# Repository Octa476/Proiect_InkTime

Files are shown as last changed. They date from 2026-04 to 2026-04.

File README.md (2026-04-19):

# Proiect_InkTime

Schematic, PCB design si 3D modeling pentru ceasul InkTime in cadrul proiectului de la materia TSC.
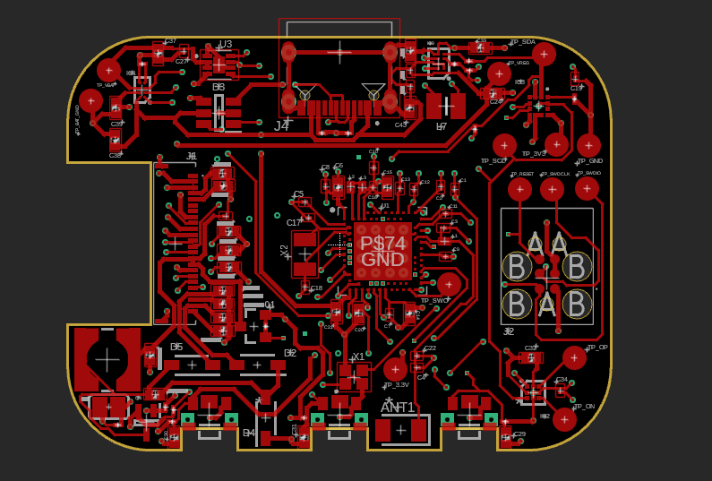
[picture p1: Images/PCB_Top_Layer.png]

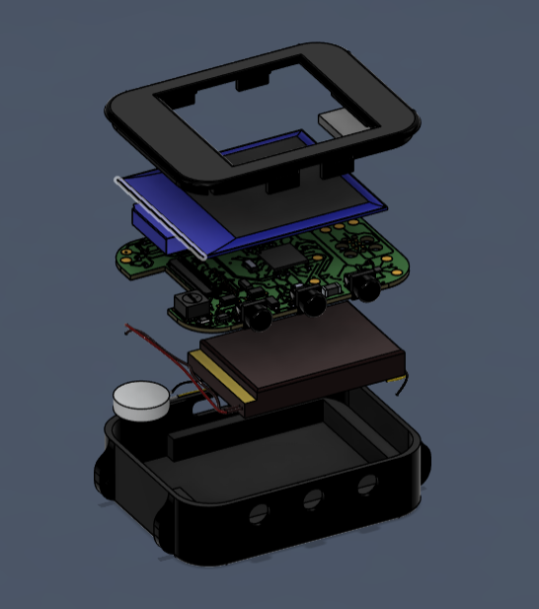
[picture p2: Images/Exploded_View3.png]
Exploded View


## Diagrama Bloc

Diagrama bloc a proietului (o varianta destul de minimala, dar suficienta pentru a intelege cum interactioneaza componentele intre ele) este prezenta in folder-ul root proiectului in varianta HTML si a fost realizata folosind [www.drawio.com](https://www.drawio.com/).
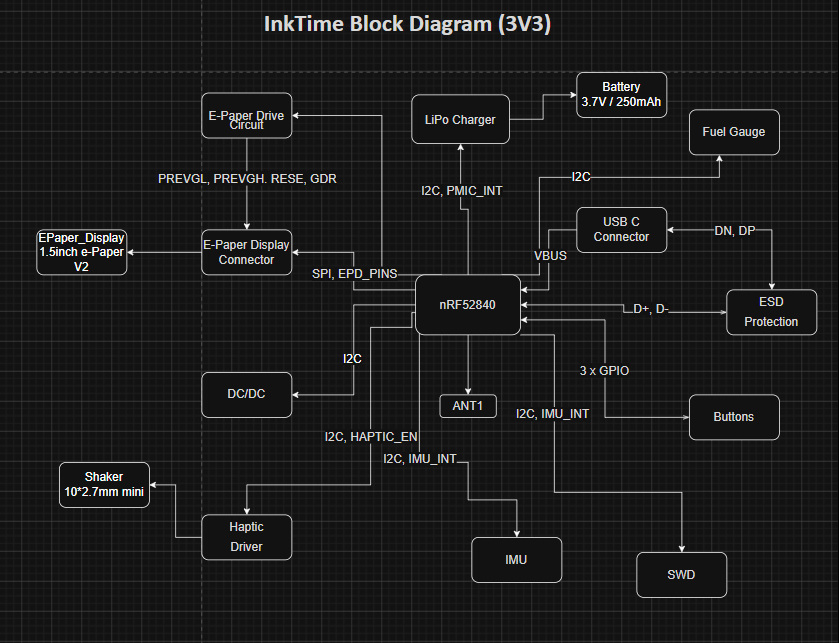
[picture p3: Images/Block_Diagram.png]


## BOM
Un Bills of Materials cu componentele folosite in cadrul acestui proiect.

### Componente active
 
| Component | Part Number | Package | Function | JLCPCB Part | Datasheet |
|---|---|---|---|---|---|
| MCU | nRF52840-QIAA-R | aQFN73 (7x7) | Microcontroller + BLE + USB | [C190794](https://jlcpcb.com/partdetail/Nordic_Semicon-NRF52840_QIAA_R/C190794) | [Datasheet](https://infocenter.nordicsemi.com/pdf/nRF52840_PS_v1.8.pdf) |
| Charger / Power Path | BQ25180YBGR | DSBGA-8 | Li-Ion/LiPo charger with power path | [C3682423](https://jlcpcb.com/partdetail/TexasInstruments-BQ25180YBGR/C3682423) | [Datasheet](https://www.ti.com/lit/ds/symlink/bq25180.pdf) |
| Buck-Boost Regulator | RT6160AWSC | WLCSP-15 | 3.3V system rail regulator | [C7065276](https://jlcpcb.com/partdetail/Richtek_Tech-RT6160AWSC/C7065276) | [Datasheet](https://www.richtek.com/assets/product_file/RT6160A/DS6160A-05.pdf) |
| Fuel Gauge | MAX17048G+T10 | DFN-8 (2x2) | Battery SOC monitoring | [C2682616](https://jlcpcb.com/partdetail/AnalogDevices-MAX17048G_T10/C2682616) | [Datasheet](https://www.analog.com/media/en/technical-documentation/data-sheets/MAX17048-MAX17049.pdf) |
| Accelerometer | BMA421 | LGA-12 (2x2) | Step counting + motion wake | [C5242966](https://jlcpcb.com/partdetail/Bosch_Sensortec-BMA421/C5242966) | [Datasheet](https://www.bosch-sensortec.com/media/boschsensortec/downloads/datasheets/bst-bma421-ds004.pdf) |
| Haptic Driver | DRV2605LDGSR | VSSOP-10 | ERM motor driver with effects library | [C527464](https://jlcpcb.com/partdetail/TexasInstruments-DRV2605LDGSR/C527464) | [Datasheet](https://www.ti.com/lit/ds/symlink/drv2605l.pdf) |
| PFET (EPD power) | SI2301CDS | SOT-23 | E-paper display power gating | [C10487](https://jlcpcb.com/partdetail/Changjiang_Electronics_Tech_CJ-SI2301CDS/C10487) | [Datasheet](https://www.vishay.com/docs/68749/si2301cds.pdf) |
| USB ESD Protection | USBLC6-2SC6Y | SOT-23-6 | ESD protection on USB data lines | [C7519](https://jlcpcb.com/partdetail/Stmicroelectronics-USBLC6_2SC6Y/C7519) | [Datasheet](https://www.st.com/resource/en/datasheet/usblc6-2.pdf) |
 
### Conectori & Componente electromecanice
 
| Component | Part Number | Package | Function | JLCPCB Part | Datasheet |
|---|---|---|---|---|---|
| FPC Connector (Display) | Molex 503480-2400 | 24-pin 0.5mm FPC | E-paper display FPC connection | [C2857160](https://jlcpcb.com/partdetail/Molex-5034802400/C2857160) | [Datasheet](https://www.molex.com/en-us/products/part-detail/5034802400) |
| USB Type-C Connector | KH-TYPE-C-16P | 16-pin SMD | USB charging + data | [C2765186](https://jlcpcb.com/partdetail/Kinghelm-KH_TYPE_C_16P/C2765186) | [Datasheet](https://datasheet.lcsc.com/lcsc/2012121836_Kinghelm-KH-TYPE-C-16P_C2765186.pdf) |
| Buttons (x3) | EVP-AKE31A | SMD tactile | Up / Down / Enter navigation | [C2845028](https://jlcpcb.com/partdetail/Panasonic-EVP_AKE31A/C2845028) | [Datasheet](https://industrial.panasonic.com/cdbs/www-data/pdf/ATV0000/ATV0000CE3.pdf) |
| SWD Debug Header | TC2030-IDC | Tag-Connect 6-pin | SWD programming + debug | - | [Datasheet](https://4donline.ihs.com/images/VipMasterIC/IC/TGCN/TGCN-S-A0008988129/TGCN-S-A0008988129-1.pdf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) |
| Antenna | 2450AT18B100E | SMD 3216 | 2.4 GHz BLE chip antenna | [C5179427](https://jlcpcb.com/partdetail/Johanson_Technology-2450AT18B100E/C5179427) | [Datasheet](https://www.johansontechnology.com/datasheets/2450AT18B100/2450AT18B100.pdf) |
 
### Componente Pasive
 
| Component | Value | Package | Qty | Function |
|---|---|---|-----|---|
| Capacitors (EPD) | 1uF/50V | 0402 | 9 | E-paper driver capacitors |
| Capacitors (decoupling) | 100nF | 0201 | 5 | MCU + peripheral decoupling |
| Capacitors (crystal load) | 12pF | 0201 | 4 | 32MHz + 32.768kHz crystal loads |
| Capacitors (bulk) | 4.7uF | 0402 | 4 | MCU power rail bulk decoupling |
| Capacitors (charger) | 1uF | 0402 | 3 | BQ25180 CIN/CSYS/CBAT |
| Capacitors (power) | 22uF | 0402 | 2 | RT6160 input capacitors |
| Capacitors (USB) | 4.7uF | 0402 | 1 | DECUSB capacitor |
| Resistors (I2C pull-up) | 10k | 0201 | 2 | I2C SDA/SCL pull-ups |
| Resistors (USB CC) | 5.1k | 0201 | 2 | USB Type-C CC1/CC2 pull-downs |
| Inductor (DC/DC) | 10uH | 0402 | 1 | nRF52840 REG1 DC/DC inductor |
| Inductor (buck-boost) | 0.47uH | 2012 | 1 | RT6160 power stage inductor |
| Crystal | 32 MHz | 2016 | 1 | HFXO for MCU + radio |
| Crystal | 32.768 kHz | 3215 | 1 | LFXO for RTC timekeeping |
 
### Componente asamblate manual
 
| Component | Description | Datasheet |
|---|---|---|
| E-Paper Display | 1.54" 200x200 e-paper panel (connected via 24-pin FPC) | [Datasheet](https://www.tme.eu/Document/0ca57a8ffbcd57b5bca53252eb9d6ec3/WSH-12561.pdf)
| LiPo Battery | 3.7V / 250mAh lithium polymer cell | [Datasheet](https://www.tme.eu/Document/b9e12bf26ad0ba929a22ab5d58f022cd/AKY0106.pdf) |
| ERM Motor | Vibration motor (LCM1027B3605F, wire-soldered) | [Datasheet](https://www.mouser.com/pdfDocs/ProductOverview_DFRobot-FIT0774.pdf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) |
| Case | 3D-printed case (SLS/MJF or FDM prototype) | [Soon](https://www.youtube.com/watch?v=xm3YgoEiEDc&list=RDxm3YgoEiEDc&start_radio=1) |

## Descrierea functionalitatii hardware

### **I2C**: LiPo Charger, DC/DC, IMU, Fuel Gauge, Haptic Driver;
### **SPI**: E-Paper Display Connector;

### Sheet1:
- **LiPo Charger** este folosit pentru a incarca bateria;
- **DC/DC** este un stabilizator de tensiune si este folosit pentru a oferi o tensiune stabila de 3V3 intregii placi;
- **IMU** este un accelerometru, fiind utilizat pentru determinarea acceleratiei pe cele 3 axe, numararea pasilor, etc;
- **nRF52840** este microcontroller-ul placutei si controleaza si orchestreaza intreaga functionalitate a acesteia;
- **SWD** - este mufa pentru conectorul de debug;

### Sheet2:
- **E-Paper Drive Circuit** este folosit pentru a controla display-ul si a oferii tensiuni de alimentare potrivite;
- **E-Paper Display Connector** - conectorul ce face legatura intre display si restul sistemului;
- **Fuel Gauge** este o componenta care indica nivelul de incarcare al bateriei;
- **USB C Connector** este mufa usb;
- **ESD Protection** este un modul ce protejeaza placuta de descarcarile elctrostatice ce pot aparea in utilizarea zilnica a ceasului;
- **Haptic Driver** este folosit pentru a controla vibratia shaker-ului;
- **Buttons** vor indeplini anumite functii in interfata cu utilizatorul (mai multe detalii in implementarea software);

## Descriere pini nRF52840 (randul de sus, sens invers trigonometric)

| Pin | Descriere |
|---|---|
| VDD | alimentarea la 3V3 |
| DCC | power regulation | 
| DEC4 | power regulation |
| VSS | GND |
| P0.31/AIN7-4 | nefolosit |
| P0.02/AIN0 | SCK - pinul de clock pentru protocolul SPI prin care comunica conectorul de display |
| P0.02/AIN0 | MOSI - master output slave in, folosit pentru comunicarea SPI |
| P1.15-12 | nefolosit |
| DEC2 | GND, power regulation |
| P1.12-11 | nefolosit |
| VDD | 3V3 |
| XC2, XC1 | pini pentru sursa de ceas X1 de 32MHz |
| DEC3 | GND |
| DEC6 | power regulation |
| VSS_PA | alimentare antena |
| ANT | pin folosit pentru legarea la antena |
| P0.10/NFC2 | pin folosit probabil pentru ca Fuel Gauge sa anunte microcontroller-ul cand tensiunea bateriei ajunse sa fie mai mica decat un prag anume |
| P0.09/NFC1 | nefolosit |
| DEC5 | GND, power regulation |
| P1.07-03 | nefolosit |
| P1.02 | buton down |
| P1.01 | controleaza tensiunea de alimentare a display-ului prin driver |
| SWDIO, SWDCLK | pini utilizati pentru depanarea si programarea microcontroller-ului |
| VDD | 3V3 |
| VSS_PAD | GND |
| P1.00 | SWO - pin utilizat pentru depanarea si programarea microcontroller-ului |
| P0.25-19 | nefolosit |
| P.18/RESET | maretul pin de reset |
| P0.17, P0.16, P0.15 | pini folositi pentru tranzactionarea cu display-ul |
| P0.13, P0.14| buton ent, buton up |
| D-, D+ | pini folositi la tranzactionarea datelor de la USB; folosesc tranmisie diferentiala |
| VBUS | alimentarea la 5V a unui USB |
| DEC3V3 | GND (ciudat putin, SoC interesant) |
| DCCH | nefolosit |
| VDDH, VDD | 3V3 |
| P0.12 | enable pentru driverul haptic |
| P0.11 | folosit pentru atentiona microcontroller-ul de posibile hazarde de alimentare; este controlar de Lipo Charger |
| P1.09 | nefolosit |
| P1.08, P0.08 | pini de intrerupere pentru modulul de IMU |
| P0.07, P0.06 | pini folositi de protocolul I2C |
| P0.05/AIN3 | chip select pentru display |
| P0.04/AIN2, P0.27, P0.26 | nefolosit |
| XL2, XL1 | pini pentru sursa de ceas X2 de 32KHz |
| DEC1 | GND, power regulation |

## Aspecte de design

- am ales sa realizez PCB-ul pe 4 straturi. Am un plan top, unul bottom, un plan de masa pe layer-ul de sub top si un plan de 3V3 pe layer-ul de deasupra lui bottom;
- am pozitionat antena in partea de jos a placii, langa butoane si am decupat straturile de cupru de sub aceasta;
- am folosit via in pad si am din aceasta cauza cateva erori pe care le-am acceptat deoarece era singura solutie viabila;
- am ales sa am un nivel de detaliu mediu in cadrul modelarii 3D a bateriei, display-ului si shaker-ului
- am conectat shaker-ul si bateria prin fire la test pad-urile asociate lor;
- am curbat conectorul flex al display-ului pentru a se potrivi in concectorul de pe PCB folosind comanda bend pentru metal sheets;
- am folosit niste inlocuitori pentru modelul 3D al unor piese, deoarece nu am putut identifica un model exact al footprint-ului din schematic sau footprint-ul nu era unul specificat tehnic (ex: PERFECT_0402, JUMPER_SJ, etc);
- am realilzat un exploded view vertical, in care sunt prezente piesele dezasamblate ale ceasului;
- am inclus cateva screenshot-uri de pe parcursul dezvolatarii proiectului in folderul Images;

## Observatii personale

Proiectul a fost extrem de muncitoresc si plin de frustrari din mai multe puncte de vedere. In primul rand, nu am fost "scoliti" in a utiliza la capacitate scazuta spre medie facilitatile de care dispune aplicatia Fusion Autodesk, fapt ce a dus la un loop aproape infinit de vizionat tutoriale si incercari repetate inutile de trage o curba in spatiu pentru desenarea firelor de legatura (un umil exemplu). Mi-as fi dorit ca laboratoarele sa prezinte mai in detaliu functionalitatile esentiale in realizarea proiectului si consider ca nu este o virtute faptul ca ne-am descurcat singuri, deoarece timpul pe care il avem este deja extrem de limitat (da, am invatat multe, pe cont propriu sau prin viu grai, dar ar fi fost mult mai usor sa fim instruiti macar putin mai mult).

Dupa aceasta critica constructiva, as dorii totusi sa felicit ideea de a propune un astfel de proiect. A fost un proces interesant de design, atat la nivel de PCB, cat si modelare 3D, si simt ca m-a ajutat sa ma dezvolt pe plan ingineresc. Am invatat sa ma descurc singur, sa incerc, m-am enervat de multe ori, dar intr-un final am reusit sa fixez un fir exact in pozitia in care imi doream.
Fun fact, am avut un bug in fusion care imi bloca coada de task-uri si ajunsesem sa am in jur de 240 de task-uri in processing, fapt ce imi bloca orice incercare de a exporta un fisier 3D. Din fericire, am rezolvat aceasta problema printr-o comanda text inteligenta.

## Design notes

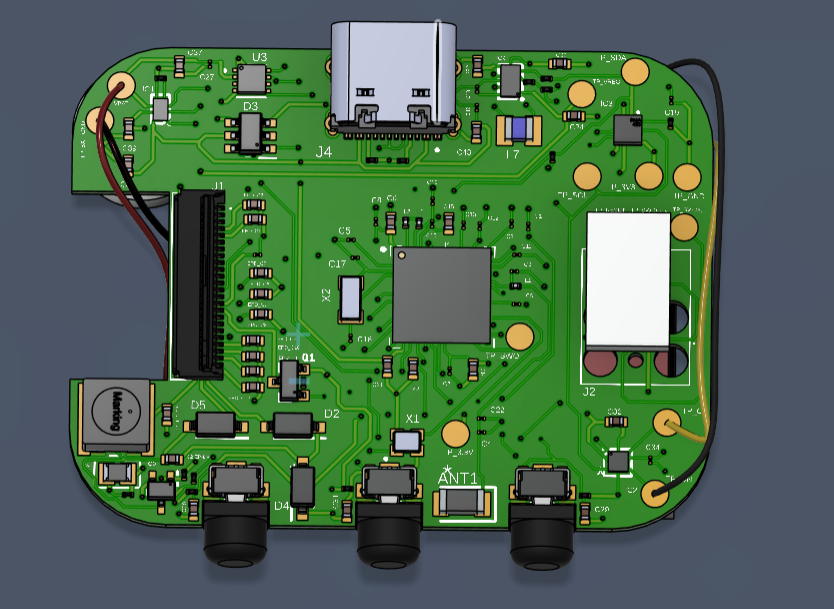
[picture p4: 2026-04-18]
Images/PCB_3D_Wires.png

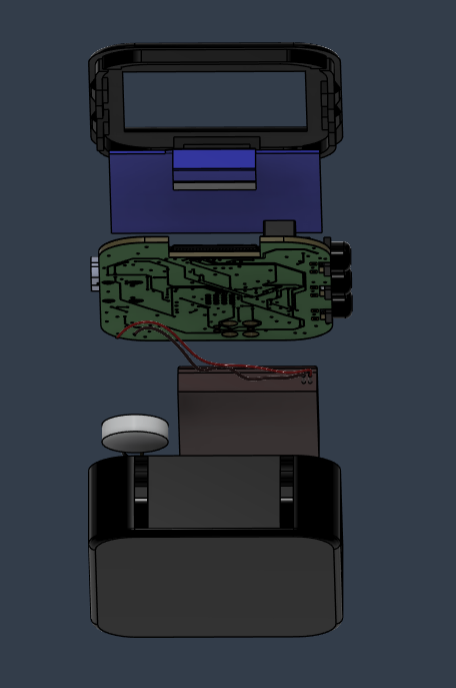
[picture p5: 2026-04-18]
Images/Exploded_View2.png

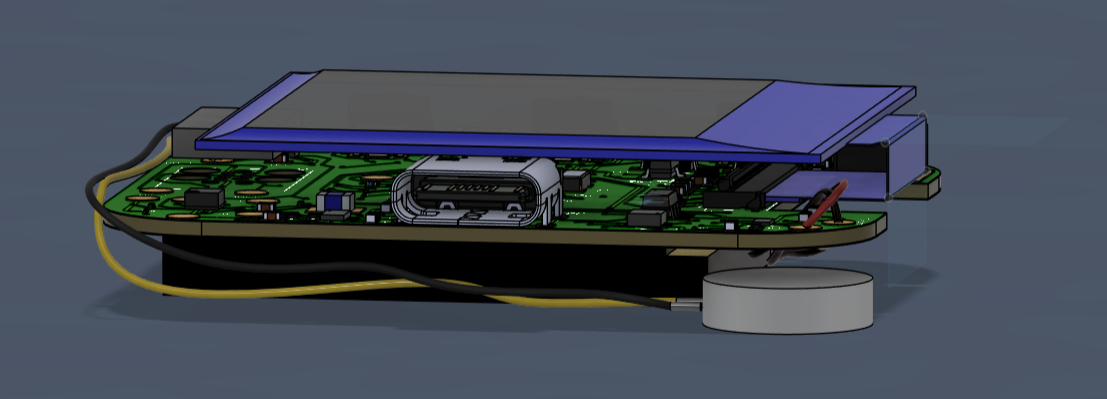
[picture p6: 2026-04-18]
Images/PCB_Side_View.png

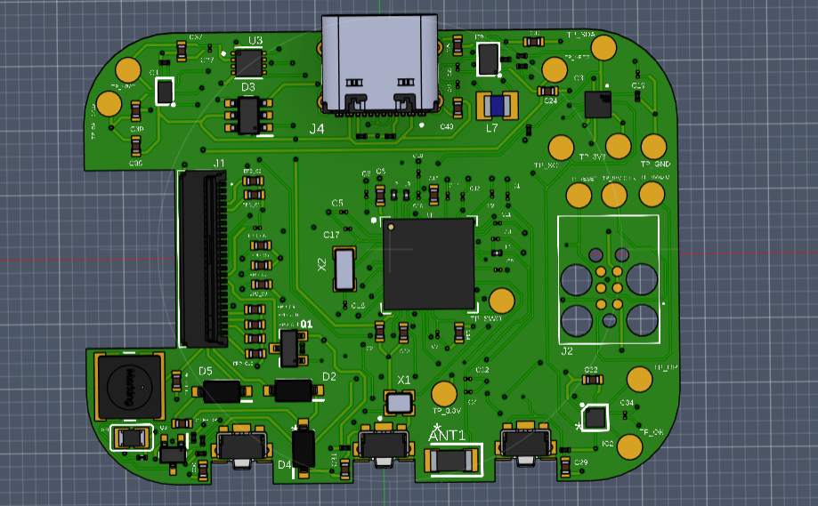
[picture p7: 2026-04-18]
Images/PCB_3D.png

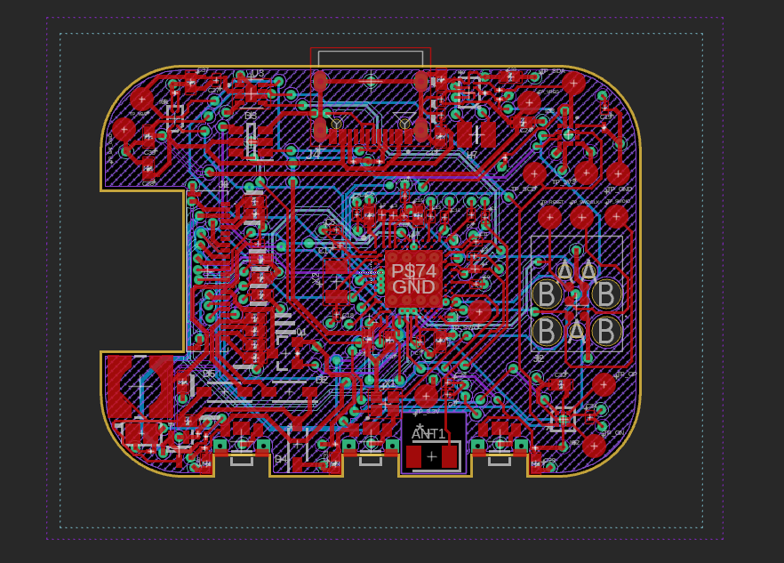
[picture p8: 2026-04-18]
Images/PCB_All_Layers.png

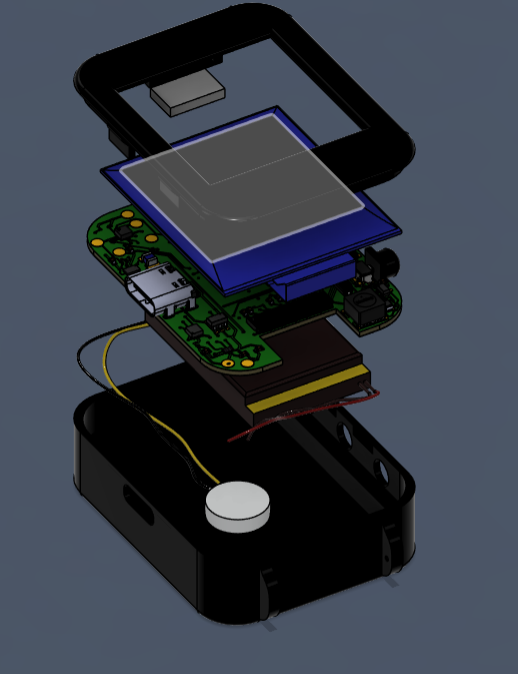
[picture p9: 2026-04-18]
Images/Exploded_View1.png

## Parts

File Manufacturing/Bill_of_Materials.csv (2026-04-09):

Qty | Value | Device | Package | Parts | Description | ARROW_PART_NUMBER | ARROW_PRICE-STOCK | AVAILABILITY | CHECK_PRICES | COPYRIGHT | DESCRIPTION | DIGI-KEY_PART_NUMBER_1 | DIGI-KEY_PART_NUMBER_2 | DIGI-KEY_PART_NUMBER_3 | HEIGHT | JLCPCB | MANUFACTURER_NAME | MANUFACTURER_PART_NUMBER | MF | MFR_NAME | MOUSER_PART_NUMBER | MOUSER_PRICE-STOCK | MP | PACKAGE | POPULARITY | PRICE | PROD_ID | PURCHASE-URL | SNAPEDA_LINK | TP_SIGNAL_NAME | VALUE
1 |  | ESP32_C6_LIBRARY_7_JUMPER_SJ | ESP32_C6_LIBRARY_7_JUMPER_SJ | SJ1 | SMD solder JUMPER |  |  |  |  |  |  |  |  |  |  |  |  |  |  |  |  |  |  |  | 3
3 | 0 | CPF0201D7K68C1_CPF0201D7K68C1 | CPF0201D7K68C1_0201 | R2, R3, R4 | 7.68k 0201 Thin Film Surface Mount Fixed Resistor +/-0.5% 0.031W CPF0201D7K68C1
4 | 0.1uF | GRM011R60J152KE01L_2_GRM011R60J152KE01L | GRM011R60J152KE01L_2_CAPC0201X13N | C23, C27, C34, C42 | Check availability |  |  | In Stock | https://www.snapeda.com/parts/GRM011R60J152KE01L/Murata/view-part/?ref=eda |  | SMD Capacitor X5R(EIA) with Capacitance: 1500pF Tol. 10%. Rated Voltage: 6.3Vdc |  |  |  |  |  |  |  | Murata |  |  |  | GRM011R60J152KE01L | 0201 Murata |  | None |  |  | https://www.snapeda.com/parts/GRM011R60J152KE01L/Murata/view-part/?ref=snap
1 | 0.1uF/50V | GRM011R60J152KE01L_2_GRM011R60J152KE01L | GRM011R60J152KE01L_2_CAPC0201X13N | EPD_C5 | Check availability |  |  | In Stock | https://www.snapeda.com/parts/GRM011R60J152KE01L/Murata/view-part/?ref=eda |  | SMD Capacitor X5R(EIA) with Capacitance: 1500pF Tol. 10%. Rated Voltage: 6.3Vdc |  |  |  |  |  |  |  | Murata |  |  |  | GRM011R60J152KE01L | 0201 Murata |  | None |  |  | https://www.snapeda.com/parts/GRM011R60J152KE01L/Murata/view-part/?ref=snap
1 | 0.47 | CPF0201D7K68C1_CPF0201D7K68C1 | CPF0201D7K68C1_0201 | R1_EP_DR | 7.68k 0201 Thin Film Surface Mount Fixed Resistor +/-0.5% 0.031W CPF0201D7K68C1
1 | 1.0uF | PERFECT_0402_CAP_0402 | PERFECT_0402_0402 | C15 | 0402 (1005 Metric)
5 | 100nF | GRM011R60J152KE01L_2_GRM011R60J152KE01L | GRM011R60J152KE01L_2_CAPC0201X13N | C5, C7, C8, C12, C19 | Check availability |  |  | In Stock | https://www.snapeda.com/parts/GRM011R60J152KE01L/Murata/view-part/?ref=eda |  | SMD Capacitor X5R(EIA) with Capacitance: 1500pF Tol. 10%. Rated Voltage: 6.3Vdc |  |  |  |  |  |  |  | Murata |  |  |  | GRM011R60J152KE01L | 0201 Murata |  | None |  |  | https://www.snapeda.com/parts/GRM011R60J152KE01L/Murata/view-part/?ref=snap
1 | 100pF | GRM011R60J152KE01L_2_GRM011R60J152KE01L | GRM011R60J152KE01L_2_CAPC0201X13N | C11 | Check availability |  |  | In Stock | https://www.snapeda.com/parts/GRM011R60J152KE01L/Murata/view-part/?ref=eda |  | SMD Capacitor X5R(EIA) with Capacitance: 1500pF Tol. 10%. Rated Voltage: 6.3Vdc |  |  |  |  |  |  |  | Murata |  |  |  | GRM011R60J152KE01L | 0201 Murata |  | None |  |  | https://www.snapeda.com/parts/GRM011R60J152KE01L/Murata/view-part/?ref=snap
6 | 10K | CPF0201D7K68C1_CPF0201D7K68C1 | CPF0201D7K68C1_0201 | R2_EP_DR, R5, R7, R8, R9, R_PWR_EPD | 7.68k 0201 Thin Film Surface Mount Fixed Resistor +/-0.5% 0.031W CPF0201D7K68C1
3 | 10uF | PERFECT_0402_CAP_0402 | PERFECT_0402_0402 | C1_EP-DR, C24, C39 | 0402 (1005 Metric)
1 | 10uH | NORDIC_NRF_2_INDUCTOR_0201_L | NORDIC_NRF_2_RESC0201_L | L2 | Generic chip inductor
4 | 12pF | GRM011R60J152KE01L_2_GRM011R60J152KE01L | GRM011R60J152KE01L_2_CAPC0201X13N | C1, C2, C17, C18 | Check availability |  |  | In Stock | https://www.snapeda.com/parts/GRM011R60J152KE01L/Murata/view-part/?ref=eda |  | SMD Capacitor X5R(EIA) with Capacitance: 1500pF Tol. 10%. Rated Voltage: 6.3Vdc |  |  |  |  |  |  |  | Murata |  |  |  | GRM011R60J152KE01L | 0201 Murata |  | None |  |  | https://www.snapeda.com/parts/GRM011R60J152KE01L/Murata/view-part/?ref=snap
1 | 15nH | NORDIC_NRF_2_INDUCTOR_0201_L | NORDIC_NRF_2_RESC0201_L | L3 | Generic chip inductor
3 | 1pF | GRM011R60J152KE01L_2_GRM011R60J152KE01L | GRM011R60J152KE01L_2_CAPC0201X13N | C3, C4, C22 | Check availability |  |  | In Stock | https://www.snapeda.com/parts/GRM011R60J152KE01L/Murata/view-part/?ref=eda |  | SMD Capacitor X5R(EIA) with Capacitance: 1500pF Tol. 10%. Rated Voltage: 6.3Vdc |  |  |  |  |  |  |  | Murata |  |  |  | GRM011R60J152KE01L | 0201 Murata |  | None |  |  | https://www.snapeda.com/parts/GRM011R60J152KE01L/Murata/view-part/?ref=snap
6 | 1uF | PERFECT_0402_CAP_0402 | PERFECT_0402_0402 | C29, C30, C31, C32, C37, C38 | 0402 (1005 Metric)
9 | 1uF/50V | PERFECT_0402_CAP_0402 | PERFECT_0402_0402 | EPD_C1, EPD_C2, EPD_C6, EPD_C7, EPD_C8, EPD_C9, EPD_C10, EPD_C11, EPD_C12 | 0402 (1005 Metric)
1 | 2.2 | CPF0201D7K68C1_CPF0201D7K68C1 | CPF0201D7K68C1_0201 | R_TYPE_SEL | 7.68k 0201 Thin Film Surface Mount Fixed Resistor +/-0.5% 0.031W CPF0201D7K68C1
3 | 2025-10-22_07-23-44_LIBRARY_EVP-AKE31ASW_EVP-AKE31A_PAN | 2025-10-22_07-23-44_LIBRARY_EVP-AKE31ASW_EVP-AKE31A_PAN | 2025-10-22_07-23-44_LIBRARY_SW_EVP-AKE31A_PAN | SW_DN, SW_ENT, SW_UP |  |  |  |  |  | Copyright (C) 2025 Ultra Librarian. All rights reserved. |  | P123437TR-ND | P123437CT-ND | P123437DKR-ND |  |  | Panasonic | EVP-AKE31A
2 | 22uF | PERFECT_0402_CAP_0402 | PERFECT_0402_0402 | C25, C33 | 0402 (1005 Metric)
1 | 2450AT18B100E | 2450AT18B100E_2450AT18B100E | 2450AT18B100E_ANTC3216X140N | ANT1 | Antennas 2.45GHz ANTENNA | 2450AT18B100E | https://www.arrow.com/en/products/2450at18b100e/johanson-dielectrics?utm_currency=USD&region=nac |  |  |  | Antennas 2.45GHz ANTENNA |  |  |  | 1.4mm |  | JOHANSON TECHNOLOGY | 2450AT18B100E |  |  | 609-2450AT18B100E | https://www.mouser.co.uk/ProductDetail/Johanson-Technology/2450AT18B100E?qs=yCnrNFeXz%252Bh5MFsFIXGZGA%3D%3D
1 | 3.9nH | NORDIC_NRF_2_INDUCTOR_0201_L | NORDIC_NRF_2_RESC0201_L | L1 | Generic chip inductor
1 | 32.768kHz | NORDIC_NRF_1_XTAL_32KHZ | NORDIC_NRF_1_XTAL_3215_N | X2
1 | 32MHz | NORDIC_NRF_XTAL_32MHZ | NORDIC_NRF_BT-XTAL_2016_N | X1
2 | 3K3 | CPF0201D7K68C1_CPF0201D7K68C1 | CPF0201D7K68C1_0201 | R17, R18 | 7.68k 0201 Thin Film Surface Mount Fixed Resistor +/-0.5% 0.031W CPF0201D7K68C1
5 | 4.7uF | PERFECT_0402_CAP_0402 | PERFECT_0402_0402 | C6, C14, C20, C21, C43 | 0402 (1005 Metric)
1 | 4.7uF/25V | PERFECT_0402_CAP_0402 | PERFECT_0402_0402 | C2-EP-DR | 0402 (1005 Metric)
1 | 47nF | GRM011R60J152KE01L_2_GRM011R60J152KE01L | GRM011R60J152KE01L_2_CAPC0201X13N | C16 | Check availability |  |  | In Stock | https://www.snapeda.com/parts/GRM011R60J152KE01L/Murata/view-part/?ref=eda |  | SMD Capacitor X5R(EIA) with Capacitance: 1500pF Tol. 10%. Rated Voltage: 6.3Vdc |  |  |  |  |  |  |  | Murata |  |  |  | GRM011R60J152KE01L | 0201 Murata |  | None |  |  | https://www.snapeda.com/parts/GRM011R60J152KE01L/Murata/view-part/?ref=snap
1 | 503480-2400 | 503480-2400_503480-2400 | 503480-2400_5034802400 | J1 | FFC & FPC Connectors 0.5mm FPC RA SMT Dual Contact 24Ckt |  |  |  |  |  | FFC & FPC Connectors 0.5mm FPC RA SMT Dual Contact 24Ckt |  |  |  | 1.87mm |  | Molex | 503480-2400 |  |  | 538-503480-2400 | https://www.mouser.co.uk/ProductDetail/Molex/503480-2400?qs=OAhjpuo3Vu7efIoxFh9AOw%3D%3D
2 | 5K1 | CPF0201D7K68C1_CPF0201D7K68C1 | CPF0201D7K68C1_0201 | R1_USB, R2_USB | 7.68k 0201 Thin Film Surface Mount Fixed Resistor +/-0.5% 0.031W CPF0201D7K68C1
1 | 68uH | ESP32_C6_LIBRARY_2_744043680IND_4828-WE-TPC_WRE | ESP32_C6_LIBRARY_2_IND_4828-WE-TPC_WRE | L5 |  |  |  |  |  | Copyright (C) 2024 Ultra Librarian. All rights reserved. |  |  |  |  |  |  |  | 744043680 |  | Wurth Electronics
1 | 820pF | GRM011R60J152KE01L_2_GRM011R60J152KE01L | GRM011R60J152KE01L_2_CAPC0201X13N | C9 | Check availability |  |  | In Stock | https://www.snapeda.com/parts/GRM011R60J152KE01L/Murata/view-part/?ref=eda |  | SMD Capacitor X5R(EIA) with Capacitance: 1500pF Tol. 10%. Rated Voltage: 6.3Vdc |  |  |  |  |  |  |  | Murata |  |  |  | GRM011R60J152KE01L | 0201 Murata |  | None |  |  | https://www.snapeda.com/parts/GRM011R60J152KE01L/Murata/view-part/?ref=snap
1 | BMA423_BMA423 | BMA423_BMA423 | BMA423_BMA423 | IC3 | Accelerometers Triaxial low-g 12bit Acceleration Sensor | BMA423 | https://www.arrow.com/en/products/bma423/bosch |  |  |  | Accelerometers Triaxial low-g 12bit Acceleration Sensor |  |  |  | 1mm |  | BOSCH | BMA423 |  |  | 262-BMA423 | https://www.mouser.co.uk/ProductDetail/Bosch-Sensortec/BMA423?qs=HXFqYaX1Q2xC%252BSgeGoX3mg%3D%3D
1 | BQ25180YBGR | BQ25180YBGR_BQ25180YBGR | BQ25180YBGR_BGA8C40P2X4_100X155X50 | IC1 | Charger IC Lithium Ion/Polymer, Lithium Iron Phosphate 8-DSBGA (1.6x1.1) | BQ25180YBGR | https://www.arrow.com/en/products/bq25180ybgr/texas-instruments?utm_currency=USD&region=nac |  |  |  | Charger IC Lithium Ion/Polymer | Lithium Iron Phosphate 8-DSBGA (1.6x1.1) |  |  |  | 0.5mm |  | Texas Instruments | BQ25180YBGR |  |  | 595-BQ25180YBGR | https://www.mouser.co.uk/ProductDetail/Texas-Instruments/BQ25180YBGR?qs=doiCPypUmgEWjAK%252BJAX6Tw%3D%3D
1 | DMG2305UX-7 20V/4.2A/52mO/1.4W | ESP32_C6_LIBRARY_4_ESP32_WROVER_SPARKFUN-DISCRETESEMI_MOSFET_PCH-DMG2305UX-7 | ESP32_C6_LIBRARY_4_ESP32_C6_LIBRARY_4_ESP32_C6_LIBRARY_4_ESP32_C6_LIBRARY_4_ESP32_WROVER_SPARKFUN-DISCRETESEMI_SOT23-3 | Q1 | P-channel MOSFETs |  |  |  |  |  |  |  |  |  |  |  |  |  |  |  |  |  |  |  |  |  | TRAN-14388 |  |  |  | 20V/4.2A/52mO/1.4W
1 | DRV2605YZFR | DRV2605YZFR_DRV2605YZFR | DRV2605YZFR_BGA9C50P3X3_144X144X62 | IC2 | Haptic Driver for ERM/LRA with Built-In Library and Smart Loop Architecture | DRV2605YZFR | https://www.arrow.com/en/products/drv2605yzfr/texas-instruments?region=nac |  |  |  | Haptic Driver for ERM/LRA with Built-In Library and Smart Loop Architecture |  |  |  | 0.625mm |  | Texas Instruments | DRV2605YZFR
1 | FTC252012SR47MBCA | MLP2016SR47MT0S1_FTC252012SR47MBCA | MLP2016SR47MT0S1_INDC2016X100N | L7 | SMD / SMT Inductors (Coils), L=0.47?H, L x W x T : |  |  |  |  |  | SMD / SMT Inductors (Coils) | L=0.47?H | L x W x T : |  |  |  | 1mm | https://jlcpcb.com/partdetail/6763488-FTC252012SR47MBCA/C5832368 | TDK | FTC252012SR47MBCA
14 | HECTOR_WATCH_1_TPTP20R | HECTOR_WATCH_1_TPTP20R | HECTOR_WATCH_1_TP20R | TP_3.3V, TP_3V3, TP_BAT_GND, TP_GND, TP_ON, TP_OP, TP_RESET, TP_SCL, TP_SDA, TP_SWDCLK, TP_SWDIO, TP_SWO, TP_VBAT, TP_VREG | Test pad |  |  |  |  |  |  |  |  |  |  |  |  |  |  |  |  |  |  |  | 2
1 | KH-TYPE-C-16P | KH-TYPE-C-16P_KH-TYPE-C-16P | KH-TYPE-C-16P_KINGHELM_KH-TYPE-C-16P | J4 | Check availability |  |  | Not in stock | https://www.snapeda.com/parts/KH-TYPE-C-16P/Kinghelm/view-part/?ref=eda |  |  |  |  |  |  |  |  |  | kinghelm |  |  |  | KH-TYPE-C-16P | None |  | None |  |  | https://www.snapeda.com/parts/KH-TYPE-C-16P/Kinghelm/view-part/?ref=snap
1 | MAX17048G+T10 | ESP32_C6_LIBRARY_MAX17048G+T10 | ESP32_C6_LIBRARY_SON50P200X200X80-9N | U3 | Check availability |  |  | In Stock | https://www.snapeda.com/parts/MAX17048G+T10/Analog+Devices/view-part/?ref=eda |  | 3µA 1-Cell/2-Cell Fuel Gauge with ModelGauge |  |  |  |  |  |  |  | Analog Devices |  |  |  | MAX17048G+T10 | TDFN-8 Maxim |  | None |  | https://www.snapeda.com/api/url_track_click_mouser/?unipart_id=329239&manufacturer=Analog Devices&part_name=MAX17048G+T10&search_term=None | https://www.snapeda.com/parts/MAX17048G+T10/Analog+Devices/view-part/?ref=snap
3 | MBR0530 | ESP32_C6_LIBRARY_5_MBR0530 | ESP32_C6_LIBRARY_5_SOD3716X135N | D2, D4, D5 | ON SEMICONDUCTOR - MBR0530 - DIODE, SCHOTTKY, 0.5A, 30V, SOD-123 |  |  | In Stock | https://www.snapeda.com/parts/MBR0530/Onsemi/view-part/?ref=eda |  | Diode Schottky 30 V 500mA Surface Mount SOD-123 |  |  |  |  |  |  |  | ON Semiconductor |  |  |  | MBR0530 | SOD-123-2 ON Semiconductor |  | None |  | https://www.snapeda.com/api/url_track_click_mouser/?unipart_id=179458&manufacturer=ON Semiconductor&part_name=MBR0530&search_term=None | https://www.snapeda.com/parts/MBR0530/Onsemi/view-part/?ref=snap
2 | N.C. | GRM011R60J152KE01L_2_GRM011R60J152KE01L | GRM011R60J152KE01L_2_CAPC0201X13N | C10, C13 | Check availability |  |  | In Stock | https://www.snapeda.com/parts/GRM011R60J152KE01L/Murata/view-part/?ref=eda |  | SMD Capacitor X5R(EIA) with Capacitance: 1500pF Tol. 10%. Rated Voltage: 6.3Vdc |  |  |  |  |  |  |  | Murata |  |  |  | GRM011R60J152KE01L | 0201 Murata |  | None |  |  | https://www.snapeda.com/parts/GRM011R60J152KE01L/Murata/view-part/?ref=snap
1 | NRF52840_QF | NORDIC_NRF_4_NRF52840_QF | NORDIC_NRF_4_AQFN50P700X700X85_HS-74N | U1 | nRF52840
1 | RT6160AWSC | RT6160AWSC_RT6160AWSC | RT6160AWSC_BGA15C40P3X5_140X230X60 | IC9 | Buck-Boost Regulator Positive Output Step-Up/Step-Down I2C DC-DC Controller IC 15-WL-CSP (BSC) (1.4x2.3) |  |  |  |  |  | Buck-Boost Regulator Positive Output Step-Up/Step-Down I2C DC-DC Controller IC 15-WL-CSP (BSC) (1.4x2.3) |  |  |  | 0.6mm |  | RICHTEK | RT6160AWSC |  |  | 835-RT6160AWSC | https://www.mouser.co.uk/ProductDetail/Richtek/RT6160AWSC?qs=amGC7iS6iy%2FLd9PSoixZXQ%3D%3D
1 | SI1308EDL-T1-GE3 | ESP32_C6_LIBRARY_6_SI1308EDL-T1-GE3 | ESP32_C6_LIBRARY_6_SOT65P210X110-3N | Q3 | MOSFET N-Ch 30V 1.5A TrenchFET SC70 Vishay Si1308EDL-T1-GE3 N-channel MOSFET Transistor, 1.5 A, 30 V, 3-Pin SC-70 |  |  | In Stock | https://www.snapeda.com/parts/SI1308EDL-T1-GE3/Vishay+Siliconix/view-part/?ref=eda |  | Si1308EDL-T1-GE3 N-channel MOSFET Transistor | 1.5 A | 30 V | 3-Pin SC-70 | Siliconix / Vishay SI1308EDL-T1-GE3 |  |  |  |  |  |  |  | Vishay Siliconix |  |  |  | SI1308EDL-T1-GE3 | SOT-323 Vishay Semiconductor |  | None |  | https://www.snapeda.com/api/url_track_click_mouser/?unipart_id=274603&manufacturer=Vishay Siliconix&part_name=SI1308EDL-T1-GE3&search_term=None
1 | TC2030-IDC | TC2030-IDC_TC2030-IDC | TC2030-IDC_TC2030IDC | J2 | CABLE ADAPTER 6 POS |  |  |  |  |  | CABLE ADAPTER 6 POS |  |  |  | 19mm |  | Tag Connect | TC2030-IDC
1 | USBLC6-2SC6Y | ESP32_C6_LIBRARY_3_USBLC6-2SC6Y | ESP32_C6_LIBRARY_3_SOT95P280X145-6N | D3 | Low Cap. ESD Protection Auto SOT-23-6 STMicroelectronics USBLC6-2SC6Y, Dual Uni-Directional TVS Diode Array, 6-Pin SOT-23 |  |  | In Stock | https://www.snapeda.com/parts/USBLC6-2SC6Y/STMicroelectronics/view-part/?ref=eda |  | 17V Clamp 5A (8/20µs) Ipp Tvs Diode Surface Mount SOT-23-6 |  |  |  |  |  |  |  | STMicroelectronics |  |  |  | USBLC6-2SC6Y | SOT-23-6 STMicroelectronics |  | None |  |  | https://www.snapeda.com/parts/USBLC6-2SC6Y/STMicroelectronics/view-part/?ref=snap

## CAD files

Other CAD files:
Mechanical/InkTime_Device.f3z

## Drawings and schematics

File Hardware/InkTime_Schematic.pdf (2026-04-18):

# LiPo Charger

1 2 C18

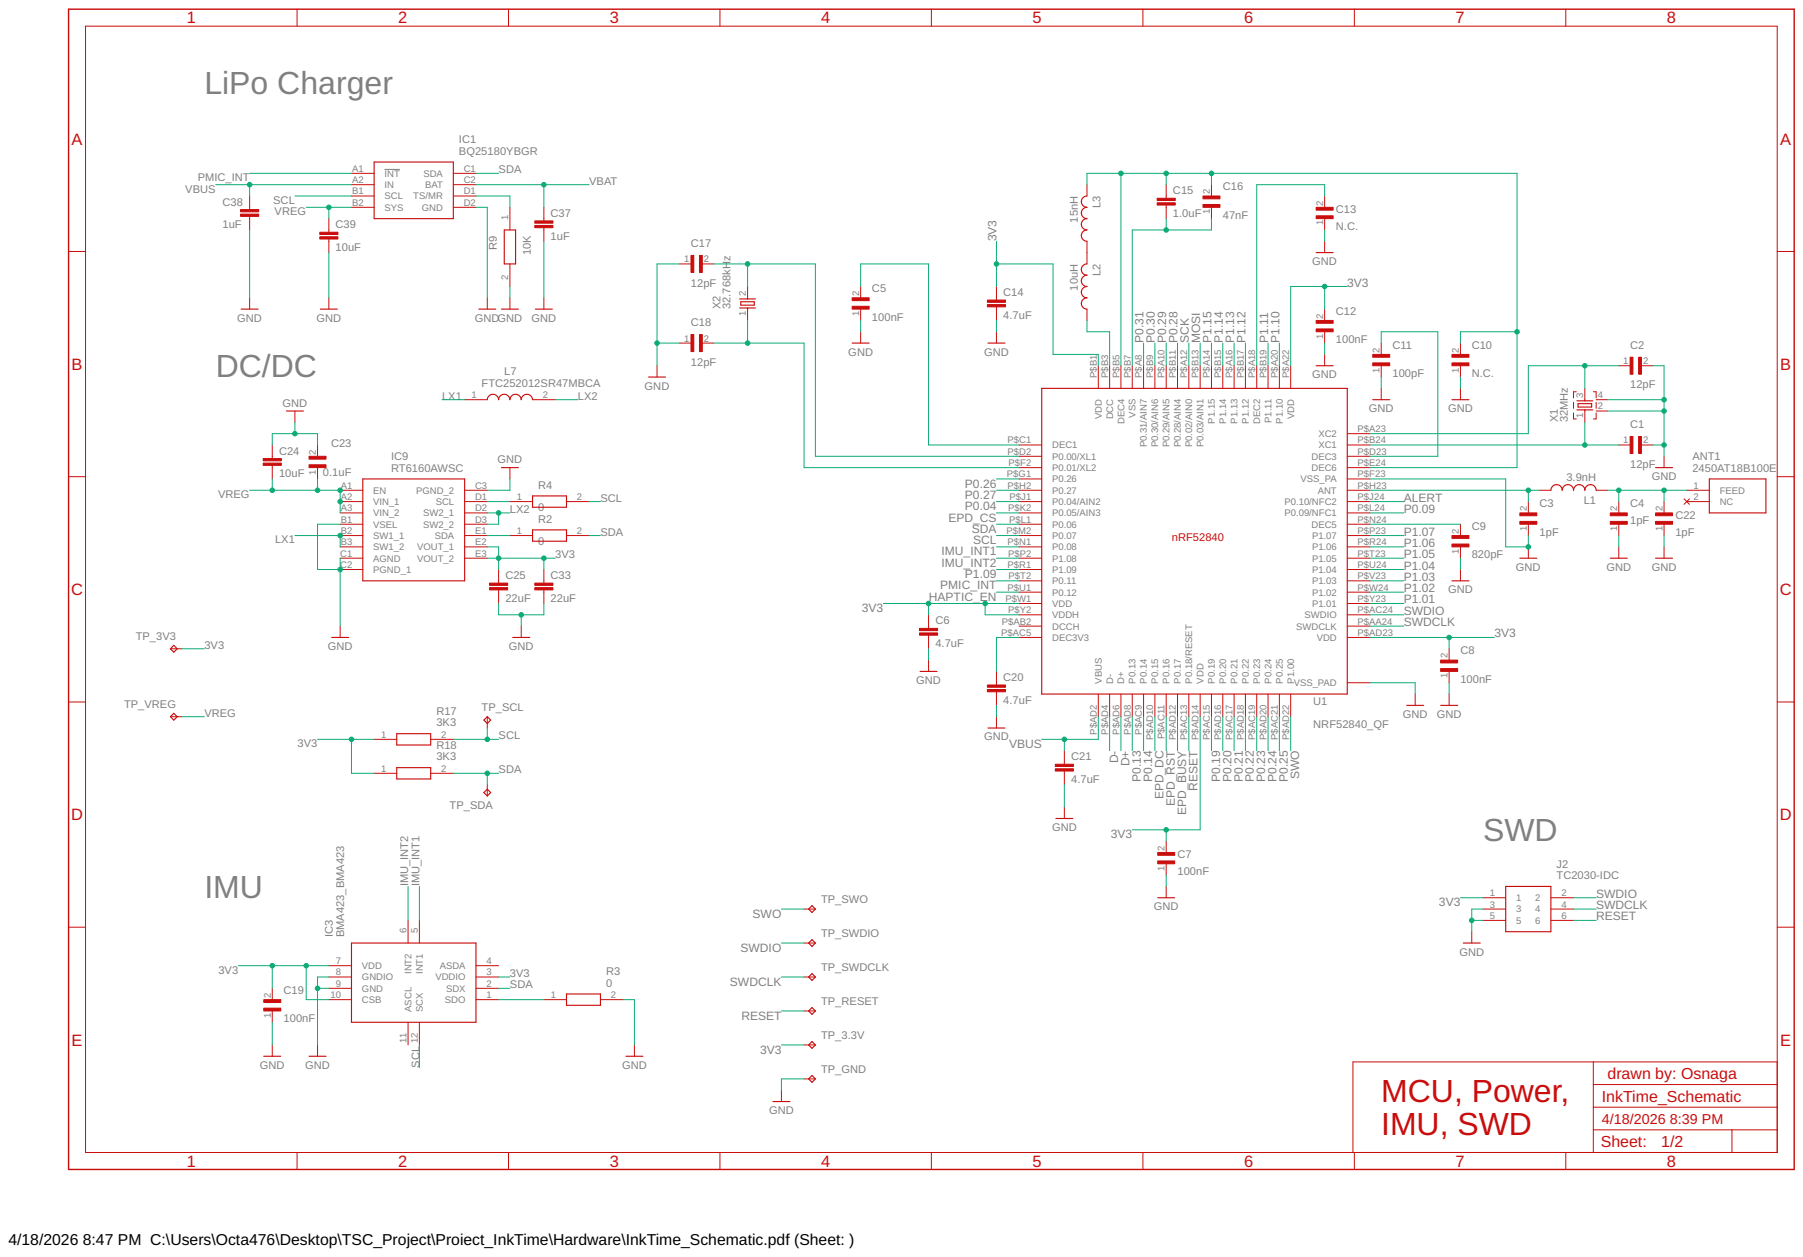
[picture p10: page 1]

4/18/2026 8:47 PM C:\Users\Octa476\Desktop\TSC_Project\Proiect_InkTime\Hardware\InkTime_Schematic.pdf (Sheet: )

# E-Paper Drive Circuit Haptic

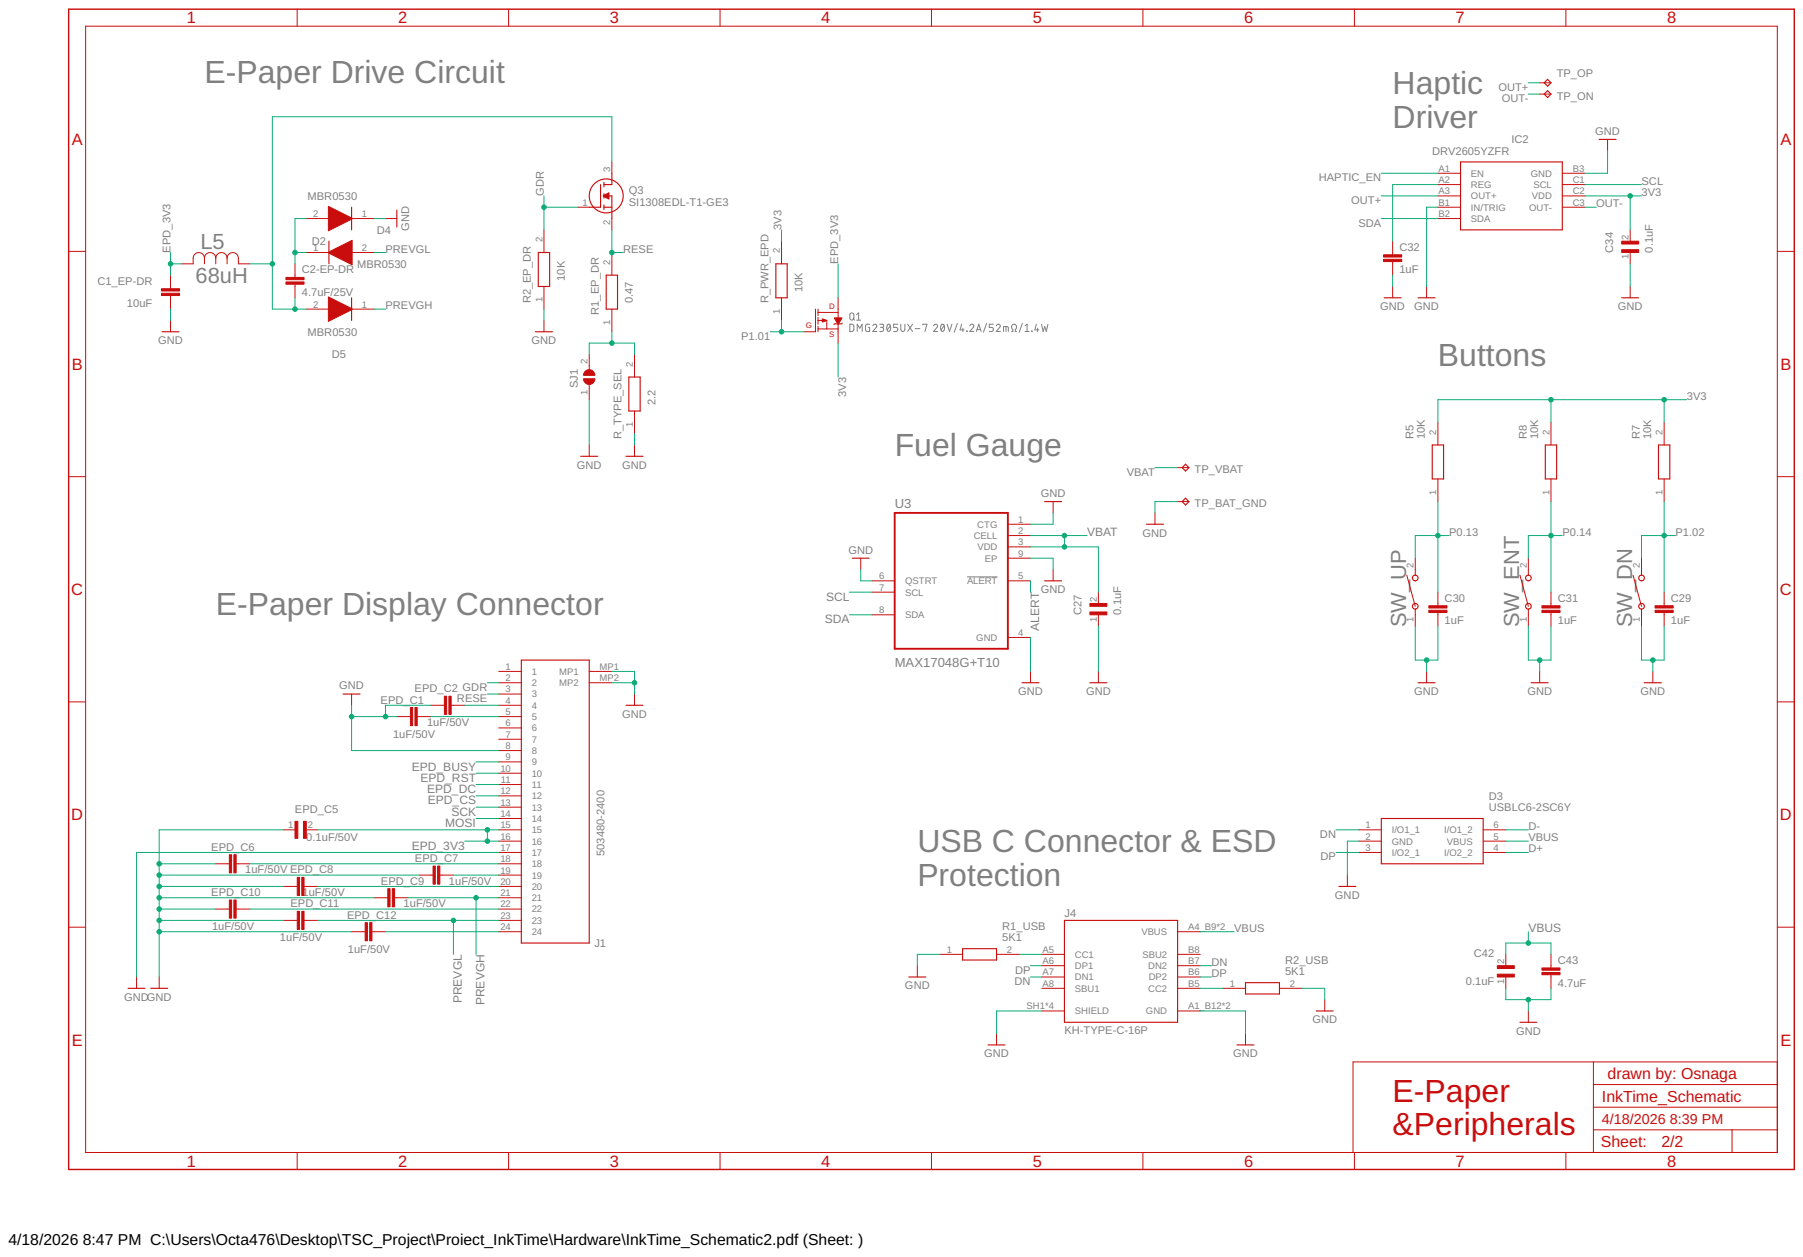
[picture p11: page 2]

1uF/50V EPD_C8 | 19
EPD_C10 | 1uF/50V | 21

EPD_C7 18
EPD_C9 | 1uF/50V 20

EPD_C11 | 1uF/50V | 22

EPD_C12 | 23

4/18/2026 8:47 PM C:\Users\Octa476\Desktop\TSC_Project\Proiect_InkTime\Hardware\InkTime_Schematic2.pdf (Sheet: )

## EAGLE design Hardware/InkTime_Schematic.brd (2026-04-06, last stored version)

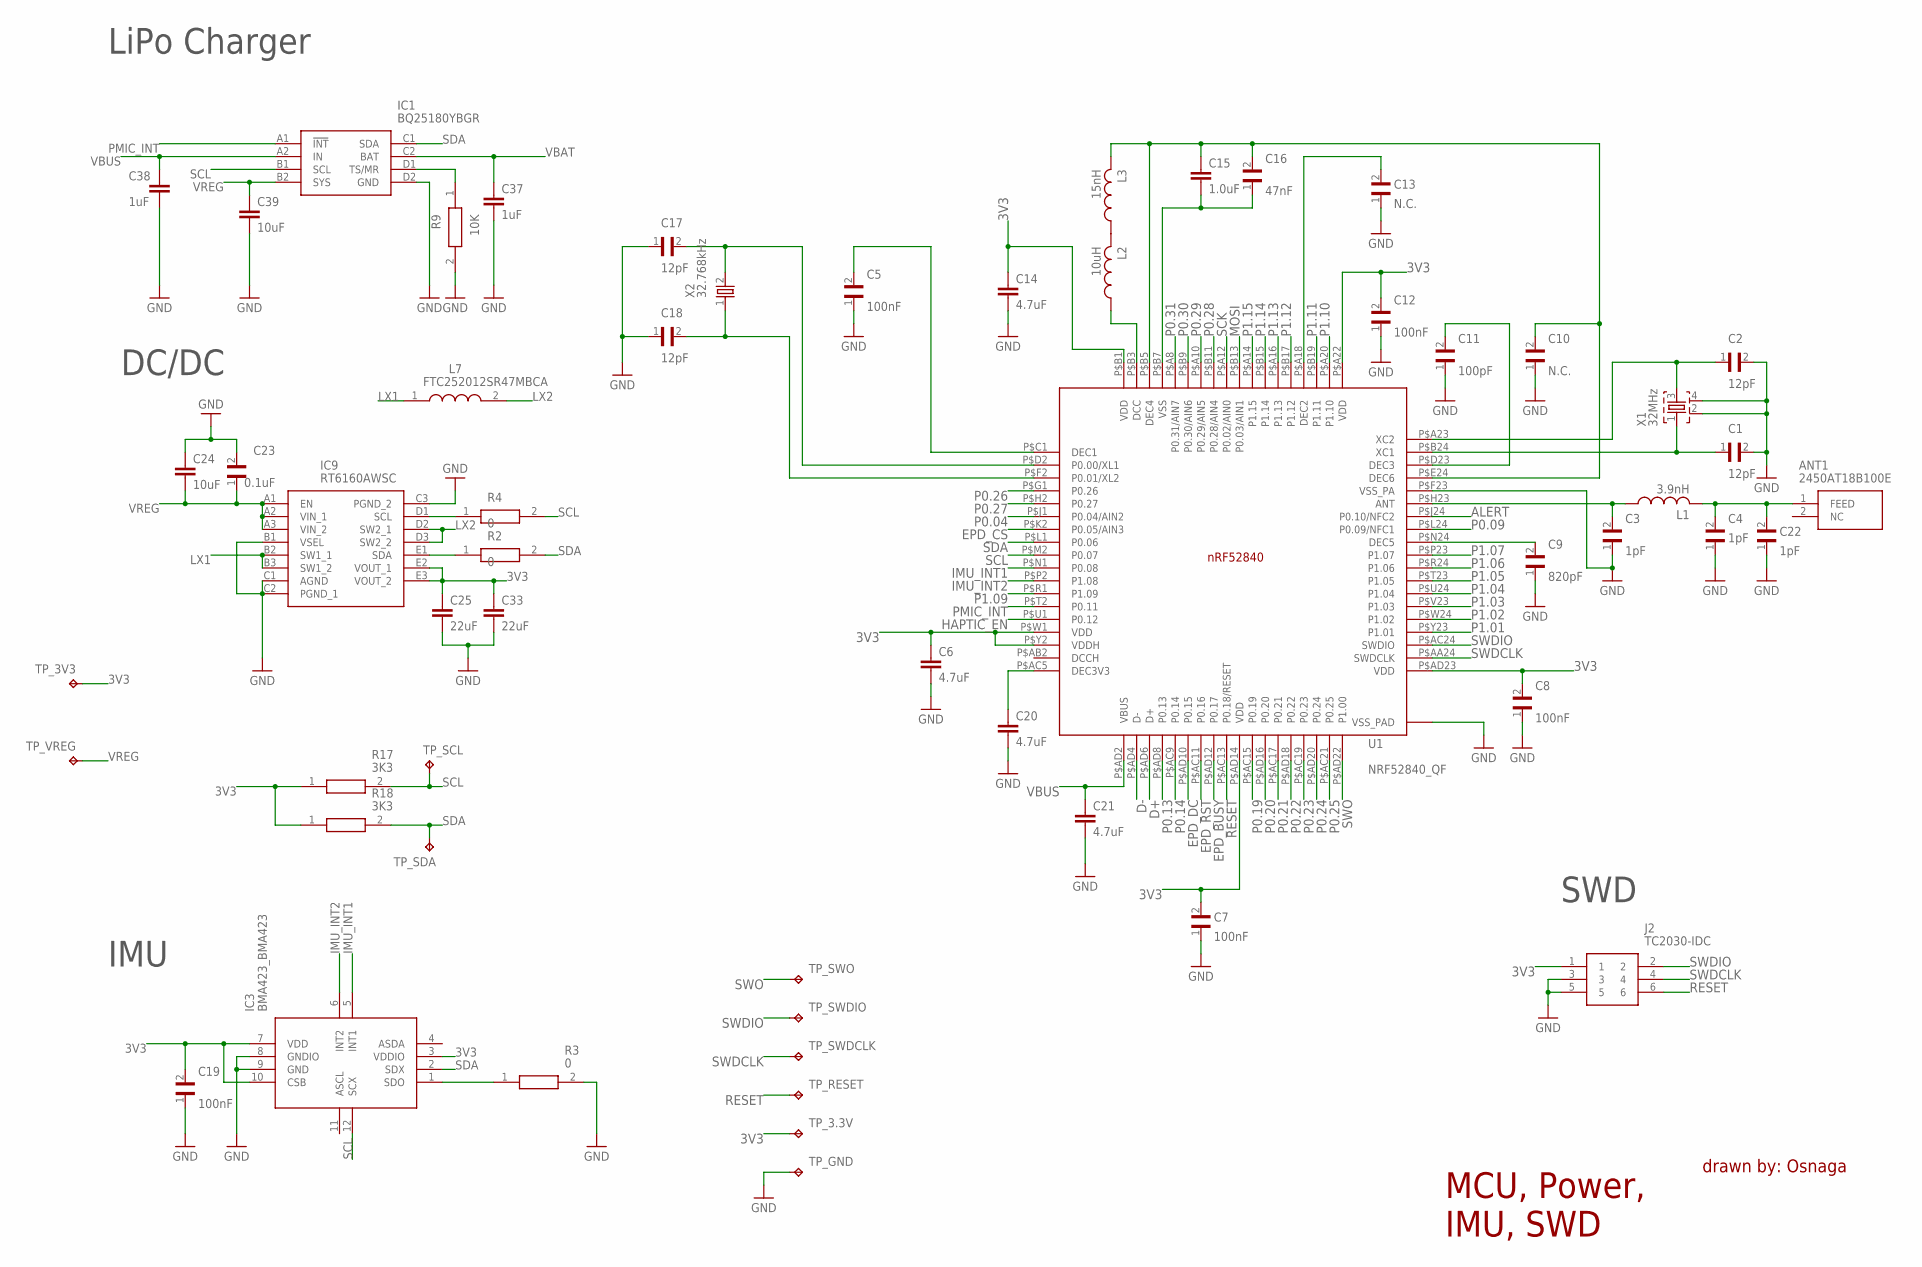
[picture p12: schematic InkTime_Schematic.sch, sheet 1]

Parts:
ANT1: 2450AT18B100E; 2450AT18B100E_ANTC3216X140N
C1, C2, C17, C18: 12pF; GRM011R60J152KE01L_2_CAPC0201X13N
C3, C4, C22: 1pF; GRM011R60J152KE01L_2_CAPC0201X13N
C5, C7, C8, C12, C19: 100nF; GRM011R60J152KE01L_2_CAPC0201X13N
C6, C14, C20, C21: 4.7uF; PERFECT_0402_0402
C9: 820pF; GRM011R60J152KE01L_2_CAPC0201X13N
C10, C13: N.C.; GRM011R60J152KE01L_2_CAPC0201X13N
C11: 100pF; GRM011R60J152KE01L_2_CAPC0201X13N
C15: 1.0uF; PERFECT_0402_0402
C16: 47nF; GRM011R60J152KE01L_2_CAPC0201X13N
C23: 0.1uF; GRM011R60J152KE01L_2_CAPC0201X13N
C24, C39: 10uF; PERFECT_0402_0402
C25, C33: 22uF; PERFECT_0402_0402
C37, C38: 1uF; PERFECT_0402_0402
IC1: BQ25180YBGR; BQ25180YBGR_BGA8C40P2X4_100X155X50
IC3: BMA423_BMA423
IC9: RT6160AWSC; RT6160AWSC_BGA15C40P3X5_140X230X60
J2: TC2030-IDC; TC2030-IDC_TC2030IDC
L1: 3.9nH; NORDIC_NRF_2_RESC0201_L
L2: 10uH; NORDIC_NRF_2_RESC0201_L
L3: 15nH; NORDIC_NRF_2_RESC0201_L
L7: FTC252012SR47MBCA; MLP2016SR47MT0S1_INDC2016X100N
R2, R3, R4: 0; CPF0201D7K68C1_0201
R9: 10K; CPF0201D7K68C1_0201
R17, R18: 3K3; CPF0201D7K68C1_0201
TP_3.3V, TP_3V3: HECTOR_WATCH_1_TPTP20R; HECTOR_WATCH_1_TP20R
TP_GND: HECTOR_WATCH_1_TPTP20R; HECTOR_WATCH_1_TP20R
TP_RESET: HECTOR_WATCH_1_TPTP20R; HECTOR_WATCH_1_TP20R
TP_SCL: HECTOR_WATCH_1_TPTP20R; HECTOR_WATCH_1_TP20R
TP_SDA: HECTOR_WATCH_1_TPTP20R; HECTOR_WATCH_1_TP20R
TP_SWDCLK: HECTOR_WATCH_1_TPTP20R; HECTOR_WATCH_1_TP20R
TP_SWDIO: HECTOR_WATCH_1_TPTP20R; HECTOR_WATCH_1_TP20R
TP_SWO: HECTOR_WATCH_1_TPTP20R; HECTOR_WATCH_1_TP20R
TP_VREG: HECTOR_WATCH_1_TPTP20R; HECTOR_WATCH_1_TP20R
U1: NRF52840_QF; NORDIC_NRF_4_AQFN50P700X700X85_HS-74N
X1: 32MHz; NORDIC_NRF_BT-XTAL_2016_N
X2: 32.768kHz; NORDIC_NRF_1_XTAL_3215_N

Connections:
3V3: C6.1, C7.2, C8.2, C12.2, C14.1, C19.2, C25.1, C33.1, IC3.3 (VDDIO), IC3.7 (VDD), IC3.10 (CSB), IC9.E2 (VOUT_1), IC9.E3 (VOUT_2), J2.1, R17.1, R18.1, TP_3.3V.TP, TP_3V3.TP, U1.P$A22 (VDD), U1.P$AD14 (VDD), U1.P$AD23 (VDD), U1.P$B1 (VDD), U1.P$W1 (VDD), U1.P$Y2 (VDDH); also elsewhere on the board
ALERT: U1.P$J24 (P0.10/NFC2); also elsewhere on the board
D+: U1.P$AD6 (D+); also elsewhere on the board
D-: U1.P$AD4 (D-); also elsewhere on the board
EPD_BUSY: U1.P$AD12 (P0.17); also elsewhere on the board
EPD_CS: U1.P$K2 (P0.05/AIN3); also elsewhere on the board
EPD_DC: U1.P$AD10 (P0.15); also elsewhere on the board
EPD_RST: U1.P$AC11 (P0.16); also elsewhere on the board
GND: C1.2, C2.2, C3.1, C4.1, C5.1, C6.2, C7.1, C8.1, C9.1, C10.1, C11.1, C12.1, C13.1, C14.2, C17.1, C18.1, C19.1, C20.2, C21.2, C22.1, C23.2, C24.1, C25.2, C33.2, C37.2, C38.2, C39.2, IC1.D2 (GND), IC3.8 (GNDIO), IC3.9 (GND), IC9.B1 (VSEL), IC9.C1 (AGND), IC9.C2 (PGND_1), IC9.C3 (PGND_2), J2.3, J2.5, R3.2, R9.2, TP_GND.TP, U1.P$74 (VSS_PAD), U1.P$75 (VSS_PAD), U1.P$76 (VSS_PAD), U1.P$77 (VSS_PAD), U1.P$78 (VSS_PAD), U1.P$79 (VSS_PAD), U1.P$80 (VSS_PAD), U1.P$81 (VSS_PAD), U1.P$82 (VSS_PAD), U1.P$83 (VSS_PAD), U1.P$84 (VSS_PAD), U1.P$85 (VSS_PAD), U1.P$86 (VSS_PAD), U1.P$87 (VSS_PAD), U1.P$88 (VSS_PAD), U1.P$89 (VSS_PAD), U1.P$90 (VSS_PAD), U1.P$F23 (VSS_PA), X1.2, X1.4; also elsewhere on the board
HAPTIC_EN: U1.P$U1 (P0.12); also elsewhere on the board
IMU_INT1: IC3.5 (INT1), U1.P$N1 (P0.08)
IMU_INT2: IC3.6 (INT2), U1.P$P2 (P1.08)
LX1: IC9.B2 (SW1_1), IC9.B3 (SW1_2), L7.1
LX2: IC9.D2 (SW2_1), IC9.D3 (SW2_2), L7.2
MOSI: U1.P$B13 (P0.03/AIN1); also elsewhere on the board
unnamed: IC9.D1 (SCL), R4.1
unnamed: IC9.E1 (SDA), R2.1
unnamed: C20.1, U1.P$AC5 (DEC3V3)
unnamed: C5.2, U1.P$C1 (DEC1)
unnamed: IC3.1 (SDO), R3.1
unnamed: IC1.D1 (TS/MR), R9.1
unnamed: C17.2, U1.P$D2 (P0.00/XL1), X2.2
unnamed: L2.2, L3.1
unnamed: L2.1, U1.P$B3 (DCC)
unnamed: C18.2, U1.P$F2 (P0.01/XL2), X2.1
unnamed: C15.2, C16.1, U1.P$B7 (VSS)
unnamed: C11.2, U1.P$D23 (DEC3)
unnamed: C2.1, U1.P$A23 (XC2), X1.3
unnamed: C1.1, U1.P$B24 (XC1), X1.1
unnamed: C3.2, L1.1, U1.P$H23 (ANT)
unnamed: ANT1.1 (FEED), C4.2, C22.2, L1.2
unnamed: C13.2, U1.P$A18 (DEC2)
unnamed: C9.2, U1.P$N24 (DEC5)
unnamed: C10.2, C15.1, C16.2, L3.2, U1.P$B5 (DEC4), U1.P$E24 (DEC6)
P0.04: U1.P$J1 (P0.04/AIN2)
P0.09: U1.P$L24 (P0.09/NFC1)
P0.13: U1.P$AD8 (P0.13); also elsewhere on the board
P0.14: U1.P$AC9 (P0.14); also elsewhere on the board
P0.19: U1.P$AC15 (P0.19)
P0.20: U1.P$AD16 (P0.20)
P0.21: U1.P$AC17 (P0.21)
P0.22: U1.P$AD18 (P0.22)
P0.23: U1.P$AC19 (P0.23)
P0.24: U1.P$AD20 (P0.24)
P0.25: U1.P$AC21 (P0.25)
P0.26: U1.P$G1 (P0.26)
P0.27: U1.P$H2 (P0.27)
P0.28: U1.P$B11 (P0.28/AIN4)
P0.29: U1.P$A10 (P0.29/AIN5)
P0.30: U1.P$B9 (P0.30/AIN6)
P0.31: U1.P$A8 (P0.31/AIN7)
P1.01: U1.P$Y23 (P1.01); also elsewhere on the board
P1.02: U1.P$W24 (P1.02); also elsewhere on the board
P1.03: U1.P$V23 (P1.03)
P1.04: U1.P$U24 (P1.04)
P1.05: U1.P$T23 (P1.05)
P1.06: U1.P$R24 (P1.06)
P1.07: U1.P$P23 (P1.07)
P1.09: U1.P$R1 (P1.09)
P1.10: U1.P$A20 (P1.10)
P1.11: U1.P$B19 (P1.11)
P1.12: U1.P$B17 (P1.12)
P1.13: U1.P$A16 (P1.13)
P1.14: U1.P$B15 (P1.14)
P1.15: U1.P$A14 (P1.15)
PMIC_INT: IC1.A1 (!INT), U1.P$T2 (P0.11)
RESET: J2.6, TP_RESET.TP, U1.P$AC13 (P0.18/RESET)
SCK: U1.P$A12 (P0.02/AIN0); also elsewhere on the board
SCL: IC1.B1 (SCL), IC3.12 (SCX), R4.2, R17.2, TP_SCL.TP, U1.P$M2 (P0.07); also elsewhere on the board
SDA: IC1.C1 (SDA), IC3.2 (SDX), R2.2, R18.2, TP_SDA.TP, U1.P$L1 (P0.06); also elsewhere on the board
SWDCLK: J2.4, TP_SWDCLK.TP, U1.P$AA24 (SWDCLK)
SWDIO: J2.2, TP_SWDIO.TP, U1.P$AC24 (SWDIO)
SWO: TP_SWO.TP, U1.P$AD22 (P1.00)
VBAT: C37.1, IC1.C2 (BAT); also elsewhere on the board
VBUS: C21.1, C38.1, IC1.A2 (IN), U1.P$AD2 (VBUS); also elsewhere on the board
VREG: C23.1, C24.2, C39.1, IC1.B2 (SYS), IC9.A1 (EN), IC9.A2 (VIN_1), IC9.A3 (VIN_2), TP_VREG.TP

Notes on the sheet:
LiPo Charger
DC/DC
IMU
MCU, Power, IMU, SWD
drawn by: Osnaga
SWD

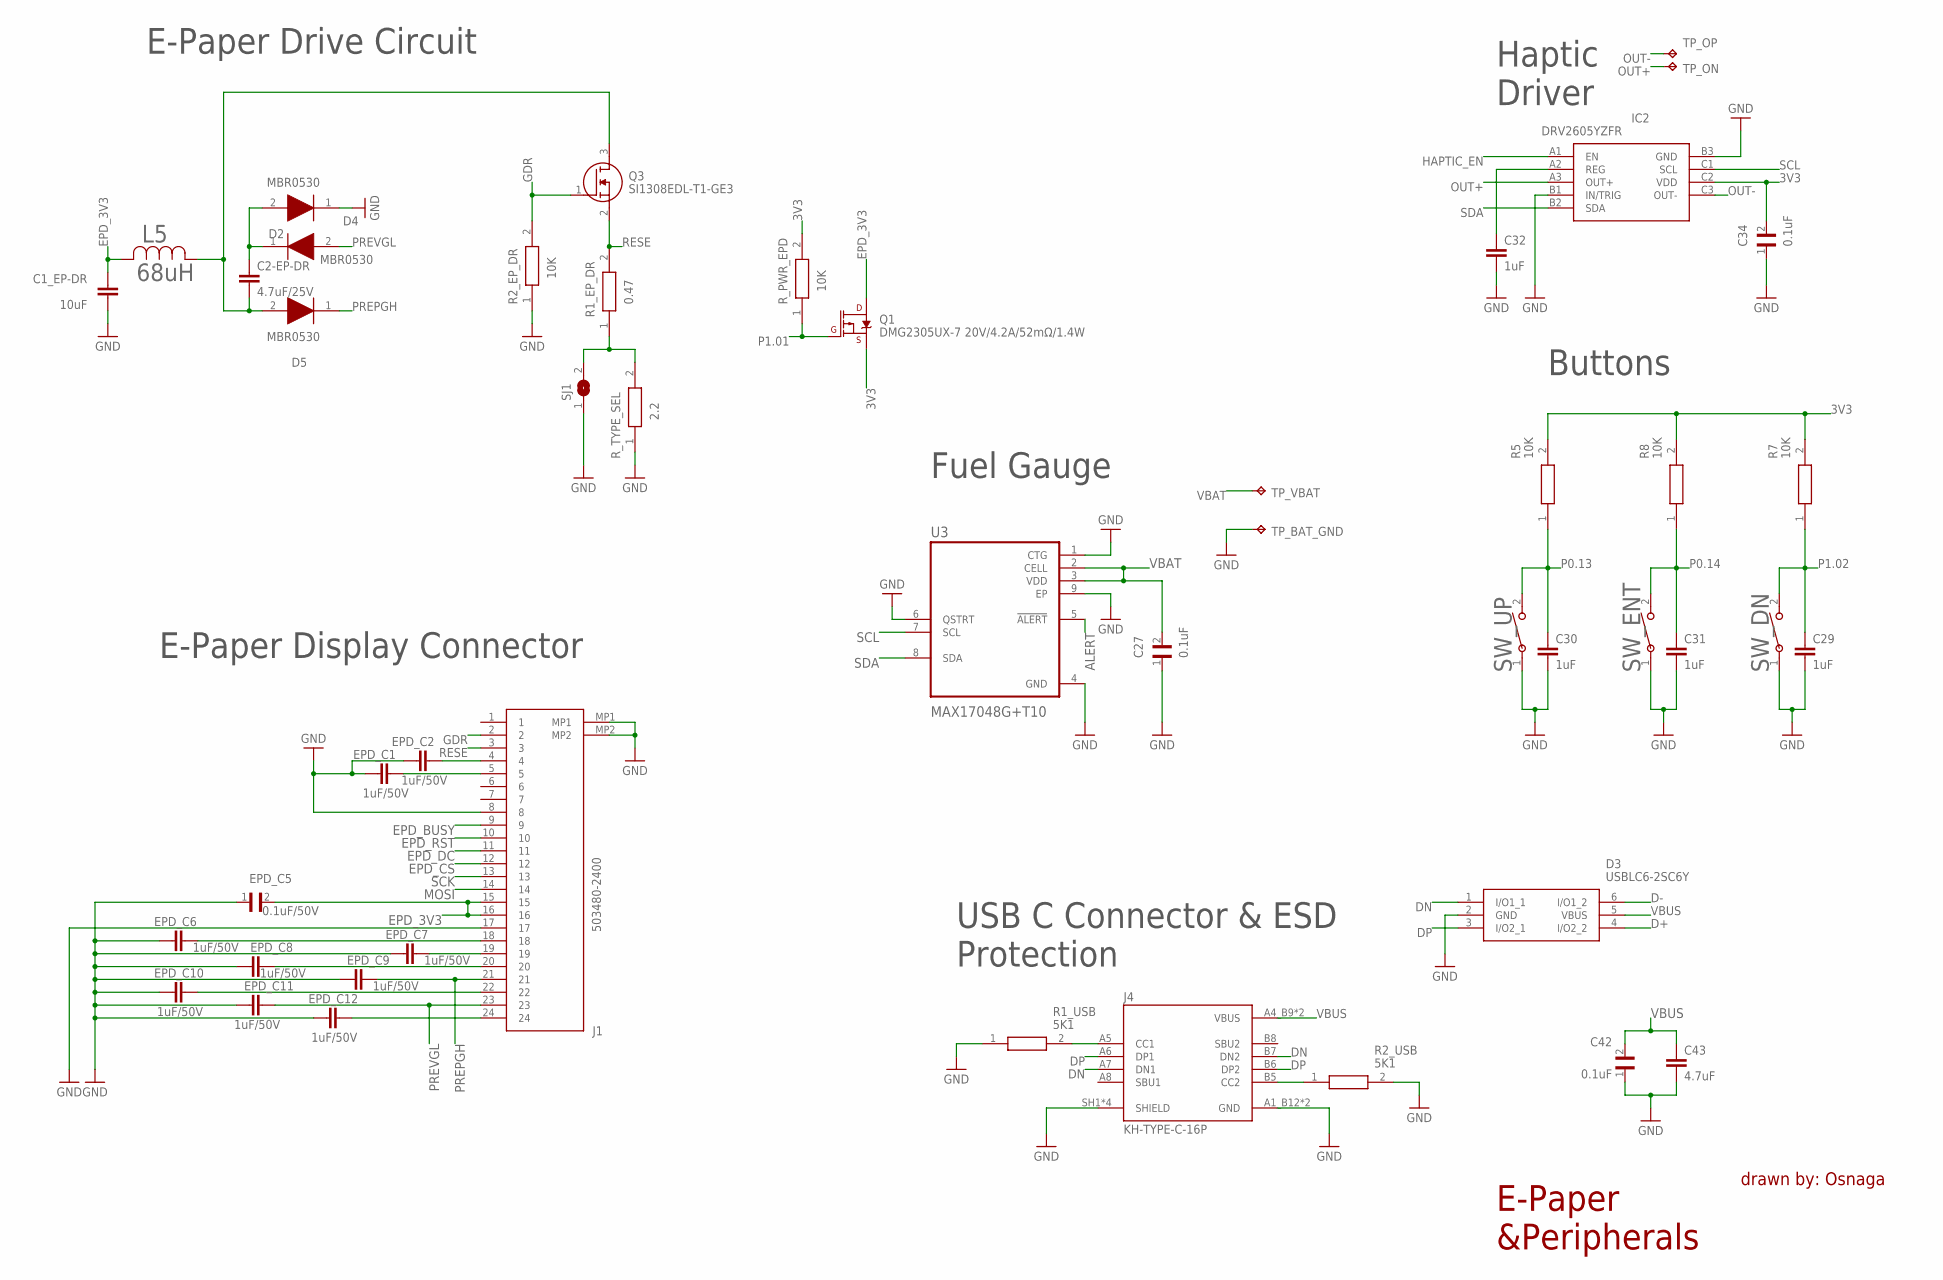
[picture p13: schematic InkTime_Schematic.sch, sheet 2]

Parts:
C1_EP-DR: 10uF; PERFECT_0402_0402
C2-EP-DR: 4.7uF/25V; PERFECT_0402_0402
C27, C34, C42: 0.1uF; GRM011R60J152KE01L_2_CAPC0201X13N
C29, C30, C31, C32: 1uF; PERFECT_0402_0402
C43: 4.7uF; PERFECT_0402_0402
D2, D4, D5: MBR0530; ESP32_C6_LIBRARY_5_SOD3716X135N
D3: USBLC6-2SC6Y; ESP32_C6_LIBRARY_3_SOT95P280X145-6N
EPD_C1, EPD_C2, EPD_C6, EPD_C7, EPD_C8, EPD_C9, EPD_C10, EPD_C11, EPD_C12: 1uF/50V; PERFECT_0402_0402
EPD_C5: 0.1uF/50V; GRM011R60J152KE01L_2_CAPC0201X13N
IC2: DRV2605YZFR; DRV2605YZFR_BGA9C50P3X3_144X144X62
J1: 503480-2400; 503480-2400_5034802400
J4: KH-TYPE-C-16P; KH-TYPE-C-16P_KINGHELM_KH-TYPE-C-16P
L5: 68uH; ESP32_C6_LIBRARY_2_IND_4828-WE-TPC_WRE
Q1: DMG2305UX-7 20V/4.2A/52mΩ/1.4W; ESP32_C6_LIBRARY_4_ESP32_C6_LIBRARY_4_ESP32_C6_LIBRARY_4_ES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
Q3: SI1308EDL-T1-GE3; ESP32_C6_LIBRARY_6_SOT65P210X110-3N
R1_EP_DR: 0.47; CPF0201D7K68C1_0201
R1_USB, R2_USB: 5K1; CPF0201D7K68C1_0201
R2_EP_DR, R5, R7, R8: 10K; CPF0201D7K68C1_0201
R_PWR_EPD: 10K; CPF0201D7K68C1_0201
R_TYPE_SEL: 2.2; CPF0201D7K68C1_0201
SJ1: ESP32_C6_LIBRARY_7_JUMPER_SJ
SW_DN: 2025-10-22_07-23-44_LIBRARY_EVP-AKE31ASW_EVP-AKE3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; 2025-10-22_07-23-44_LIBRARY_SW_EVP-AKE31A_PAN
SW_ENT: 2025-10-22_07-23-44_LIBRARY_EVP-AKE31ASW_EVP-AKE3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; 2025-10-22_07-23-44_LIBRARY_SW_EVP-AKE31A_PAN
SW_UP: 2025-10-22_07-23-44_LIBRARY_EVP-AKE31ASW_EVP-AKE3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; 2025-10-22_07-23-44_LIBRARY_SW_EVP-AKE31A_PAN
TP_BAT_GND: HECTOR_WATCH_1_TPTP20R; HECTOR_WATCH_1_TP20R
TP_ON: HECTOR_WATCH_1_TPTP20R; HECTOR_WATCH_1_TP20R
TP_OP: HECTOR_WATCH_1_TPTP20R; HECTOR_WATCH_1_TP20R
TP_VBAT: HECTOR_WATCH_1_TPTP20R; HECTOR_WATCH_1_TP20R
U3: MAX17048G+T10; ESP32_C6_LIBRARY_SON50P200X200X80-9N

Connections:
3V3: C34.2, IC2.C2 (VDD), Q1.2 (S), R5.2, R7.2, R8.2, R_PWR_EPD.2; also elsewhere on the board
ALERT: U3.5 (!ALERT); also elsewhere on the board
D+: D3.4 (I/O2_2); also elsewhere on the board
D-: D3.6 (I/O1_2); also elsewhere on the board
DN: D3.1 (I/O1_1), J4.A7 (DN1), J4.B7 (DN2)
DP: D3.3 (I/O2_1), J4.A6 (DP1), J4.B6 (DP2)
EPD_3V3: C1_EP-DR.1, EPD_C5.2, J1.15, J1.16, L5.2, Q1.3 (D)
EPD_BUSY: J1.9; also elsewhere on the board
EPD_CS: J1.12; also elsewhere on the board
EPD_DC: J1.11; also elsewhere on the board
EPD_RST: J1.10; also elsewhere on the board
GDR: J1.2, Q3.1 (G), R2_EP_DR.2
GND: C1_EP-DR.2, C27.1, C29.2, C30.2, C31.2, C32.2, C34.1, C42.1, C43.2, D3.2 (GND), D4.1 (K), EPD_C1.1, EPD_C2.1, EPD_C5.1, EPD_C6.1, EPD_C7.1, EPD_C8.1, EPD_C9.1, EPD_C10.1, EPD_C11.1, EPD_C12.1, IC2.B1 (IN/TRIG), IC2.B3 (GND), J1.8, J1.17, J1.MP1, J1.MP2, J4.A1_B12 (GND), J4.A12_B1 (GND), J4.SH1 (SHIELD), J4.SH2 (SHIELD), J4.SH3 (SHIELD), J4.SH4 (SHIELD), R1_USB.1, R2_EP_DR.1, R2_USB.2, R_TYPE_SEL.1, SJ1.1, SW_DN.1, SW_ENT.1, SW_UP.1, TP_BAT_GND.TP, U3.1 (CTG), U3.4 (GND), U3.6 (QSTRT), U3.9 (EP); also elsewhere on the board
HAPTIC_EN: IC2.A1 (EN); also elsewhere on the board
MOSI: J1.14; also elsewhere on the board
unnamed: EPD_C6.2, J1.18
unnamed: EPD_C7.2, J1.19
unnamed: EPD_C8.2, J1.20
unnamed: J4.B5 (CC2), R2_USB.1
unnamed: EPD_C10.2, J1.22
unnamed: EPD_C2.2, J1.4
unnamed: EPD_C1.2, J1.5
unnamed: EPD_C12.2, J1.24
unnamed: R1_EP_DR.1, R_TYPE_SEL.2, SJ1.2
unnamed: C2-EP-DR.2, D5.2 (A), L5.1, Q3.3 (D)
unnamed: J4.A5 (CC1), R1_USB.2
unnamed: C2-EP-DR.1, D2.1 (K), D4.2 (A)
unnamed: C32.1, IC2.A2 (REG)
OUT+: IC2.A3 (OUT+), TP_ON.TP
OUT-: IC2.C3 (OUT-), TP_OP.TP
P0.13: C30.1, R5.1, SW_UP.2; also elsewhere on the board
P0.14: C31.1, R8.1, SW_ENT.2; also elsewhere on the board
P1.01: Q1.1 (G), R_PWR_EPD.1; also elsewhere on the board
P1.02: C29.1, R7.1, SW_DN.2; also elsewhere on the board
PREPGH: D5.1 (K), EPD_C9.2, J1.21
PREVGL: D2.2 (A), EPD_C11.2, J1.23
RESE: J1.3, Q3.2 (S), R1_EP_DR.2
SCK: J1.13; also elsewhere on the board
SCL: IC2.C1 (SCL), U3.7 (SCL); also elsewhere on the board
SDA: IC2.B2 (SDA), U3.8 (SDA); also elsewhere on the board
VBAT: C27.2, TP_VBAT.TP, U3.2 (CELL), U3.3 (VDD); also elsewhere on the board
VBUS: C42.2, C43.1, D3.5 (VBUS), J4.A4_B9 (VBUS), J4.A9_B4 (VBUS); also elsewhere on the board

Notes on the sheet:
E-Paper Drive Circuit
Fuel Gauge
E-Paper Display Connector
USB C Connector & ESD Protection
Buttons
Haptic Driver
E-Paper &Peripherals
drawn by: Osnaga

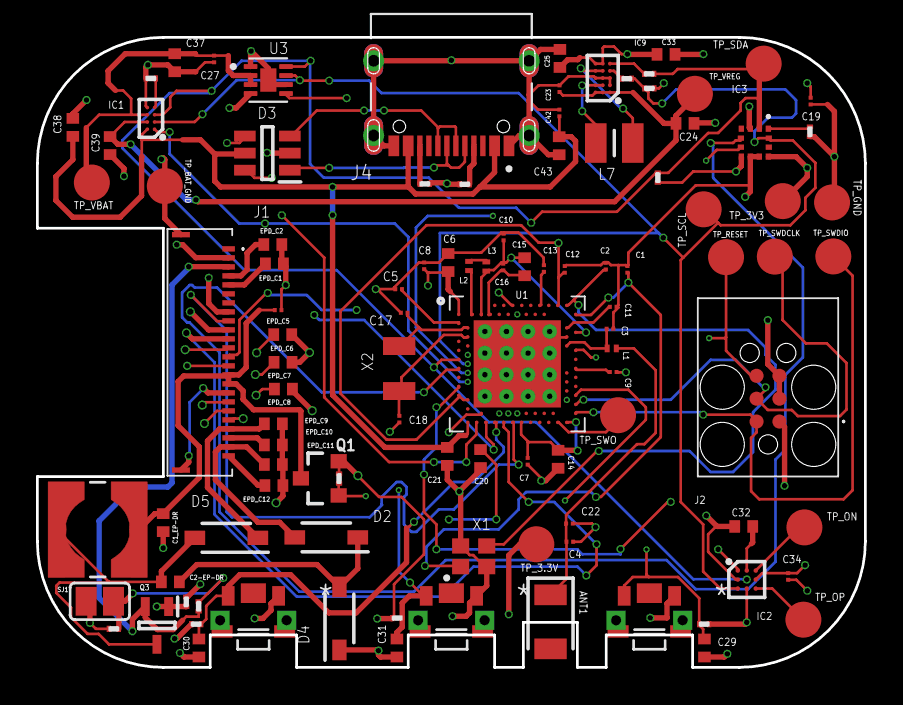
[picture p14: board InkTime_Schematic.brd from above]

Board: 4 copper layers, 46.0 x 35.0 mm, 105 parts (0 on the bottom side), 71 nets.

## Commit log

2026-03-25 Prima incercare the schematic
    [InkTime_Schematic.sch]
2026-04-06 Finished the schematic and the PCB
    [InkTime_Schematic.brd, InkTime_Schematic.sch]
2026-04-09 Finished the 3D design and exploded 3D view
    [InkTime_Device.f3z]
2026-04-09 Am adaugat fisiere de manufacturing
    [InkTime_Schematic.csv, PnP_InkTime_Schematic_front.csv]
2026-04-18 Fixed the schematic and the pcb
    [InkTime_Device.f3z, InkTime_Schematic.brd, InkTime_Schematic.csv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]
2026-04-18 Added .pdf schematic and renamed .fbrb file
2026-04-18 Added new manufacturing folder
    [Bill_of_Materials.csv, Pick_and_Place.csv]
2026-04-18 Repaired silkscreen

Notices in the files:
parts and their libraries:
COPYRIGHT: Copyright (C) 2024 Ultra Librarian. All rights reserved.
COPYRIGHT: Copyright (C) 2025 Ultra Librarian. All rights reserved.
